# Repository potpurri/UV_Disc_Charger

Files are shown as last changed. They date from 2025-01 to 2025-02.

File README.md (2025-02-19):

## Overview

This project presents a UV disc charger designed to illuminate glow-in-the-dark disc golf discs using 100 UV LEDs.

The circuit is powered by a LiPo battery, which is charged through a TP4056 with DW01A protection. The LEDs are driven by a TPS63020 buck/boost converter, and the battery is charged via a USB-C port.

**Note:** This project is a work in progress, aimed at exploring and learning more about these technologies.

## Features

The board includes the following components:

- **TP4056**: Monitors and manages the charging process.
- **DW01A Protection**: Ensures safe charging of the LiPo battery.
- **TPS63020 Buck/Boost Converter**: Efficiently drives 100 UV LEDs.
- **USB-C Port**: Enables battery charging.
- **Adjustable Charging Current**: The charging current is set using resistor R9, with the following settings:

| Resistor (Ω) | Charging Current (mA) |
|---|---|
| 10k | 130 |
| 4k7 | 280 |
| 3k | 400 |
| 2k | 580 |
| 1k5 | 780 |
| 1k2 | 1000 |

Image showing the battery being charged at approximately 500mA:

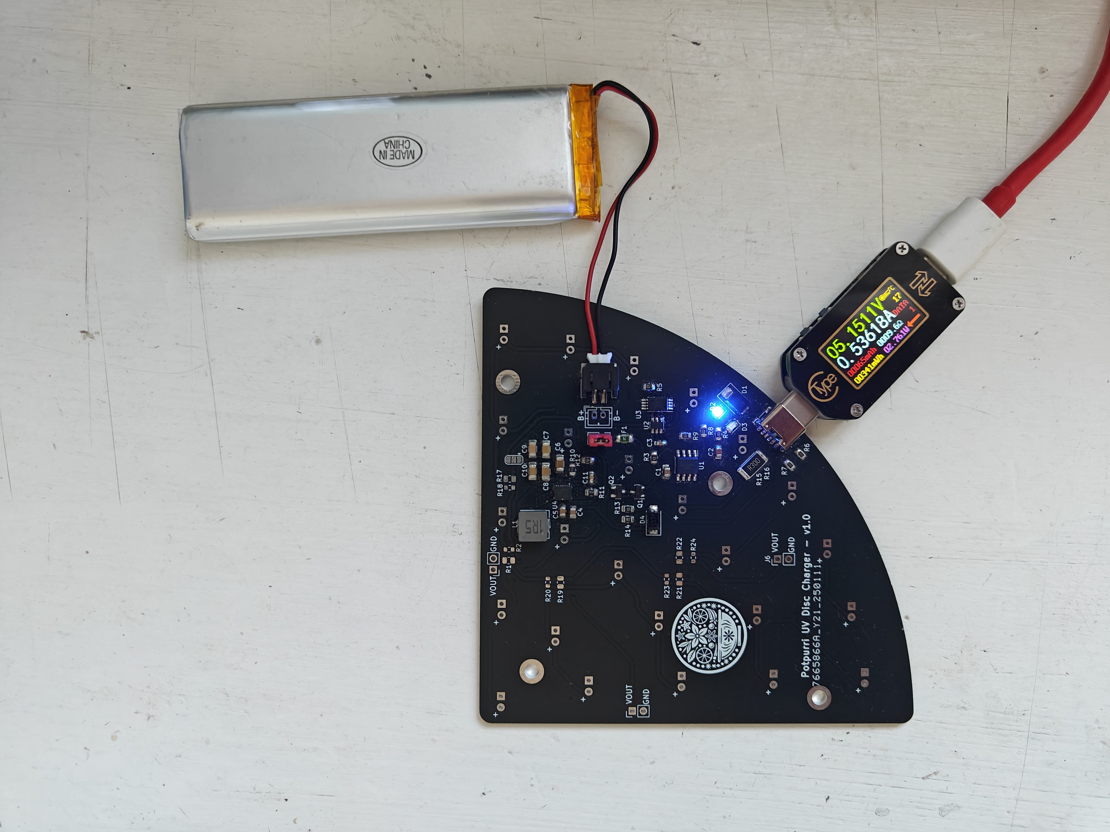
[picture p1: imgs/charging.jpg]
Charging


## Images

Below are renderings of the PCB:

3D render of the front view of the PCB

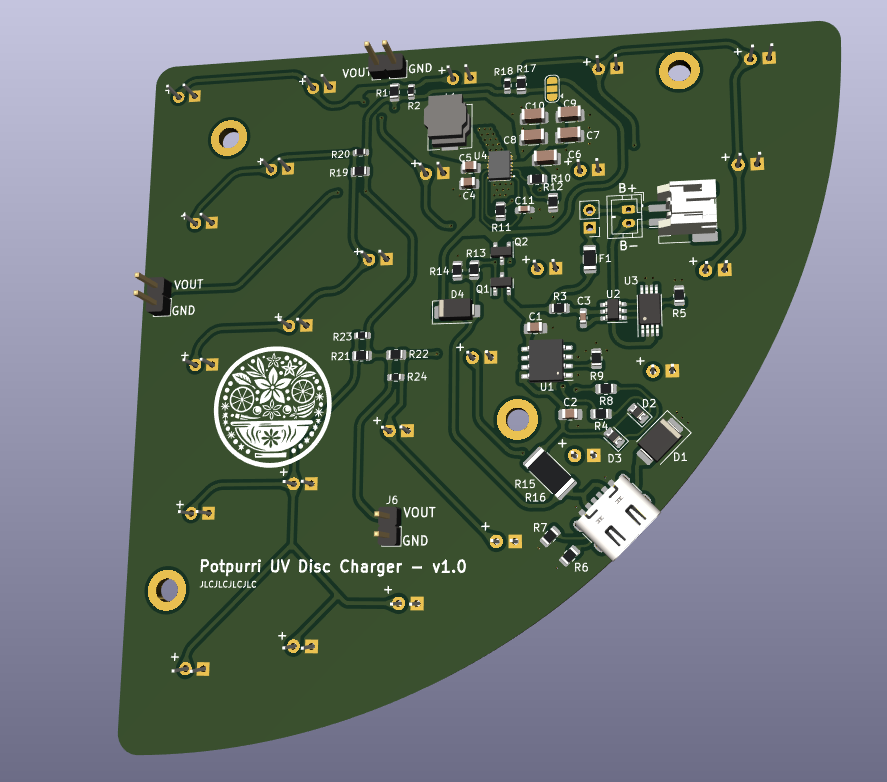
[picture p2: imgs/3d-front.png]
3D Front


3D render of the back view of the PCB

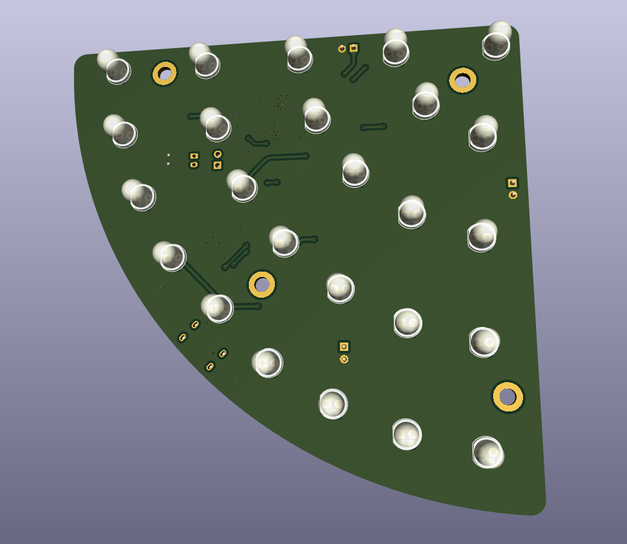
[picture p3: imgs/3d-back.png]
3D Back


Front view of the actual PCB

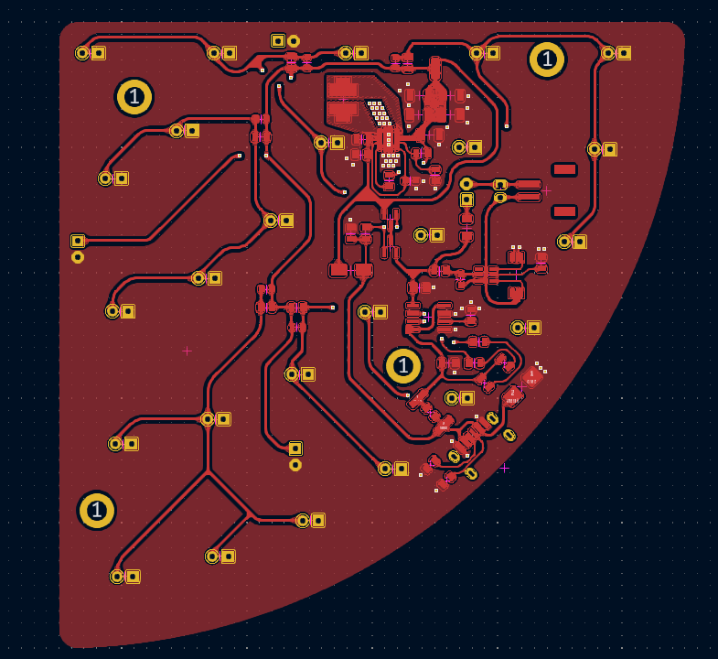
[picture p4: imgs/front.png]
Front


Back view of the actual PCB

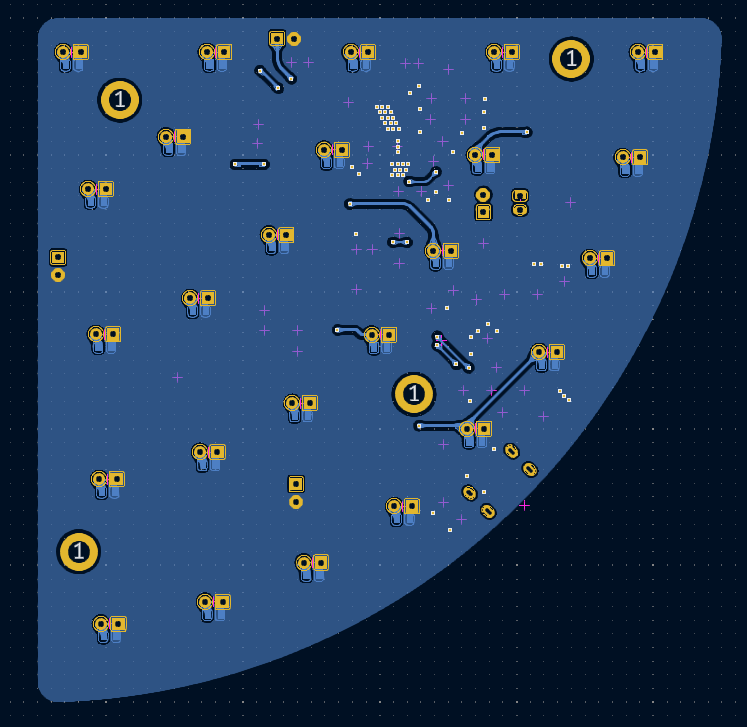
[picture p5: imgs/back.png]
Back


## Real PCB Images

Below are images of the actual PCB:

Front view of the real PCB

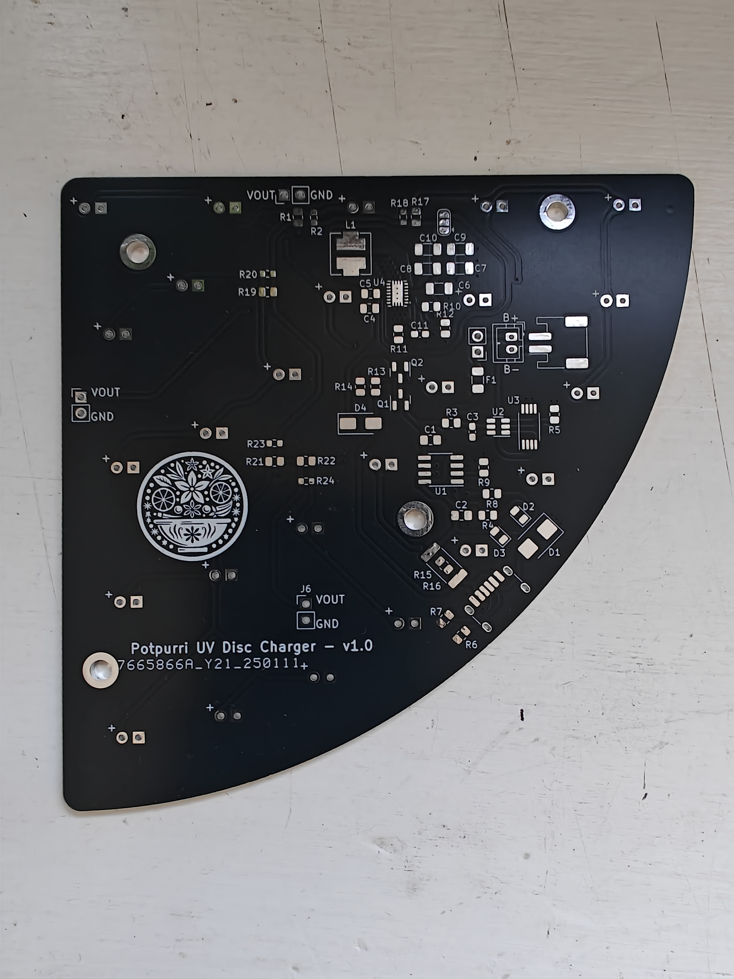
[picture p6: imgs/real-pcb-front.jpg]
Real PCB Front


Back view of the real PCB

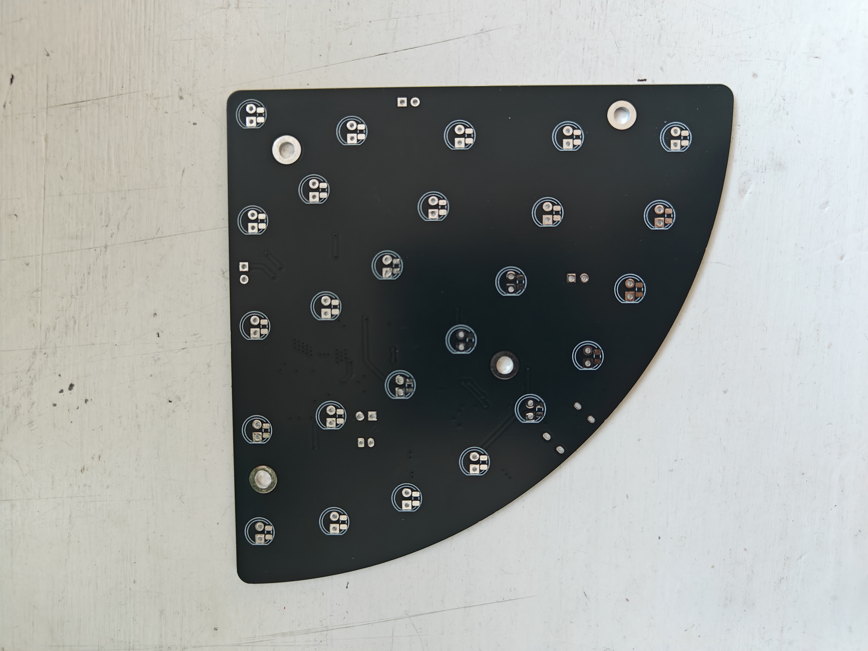
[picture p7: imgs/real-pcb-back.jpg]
Real PCB Back


## Full Assembly

**WORK IN PROGRESS**

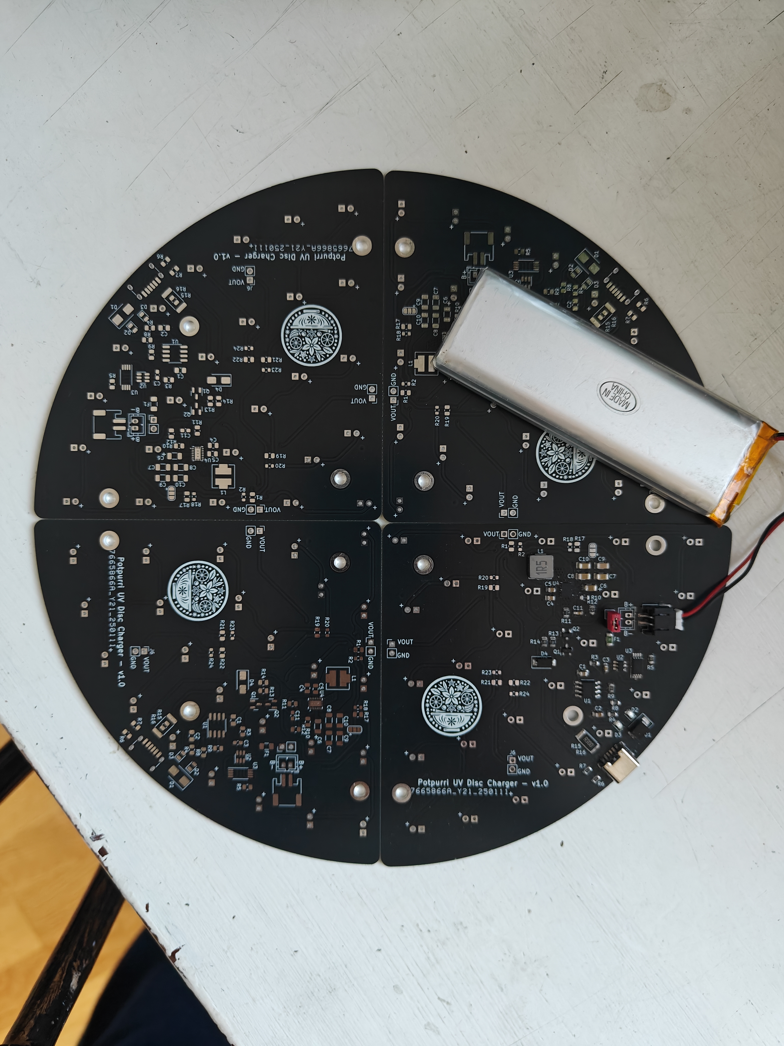
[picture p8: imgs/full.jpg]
Full Assembly


## Schematics

For detailed schematics, please refer to the [schematic PDF](imgs/schematic.pdf).

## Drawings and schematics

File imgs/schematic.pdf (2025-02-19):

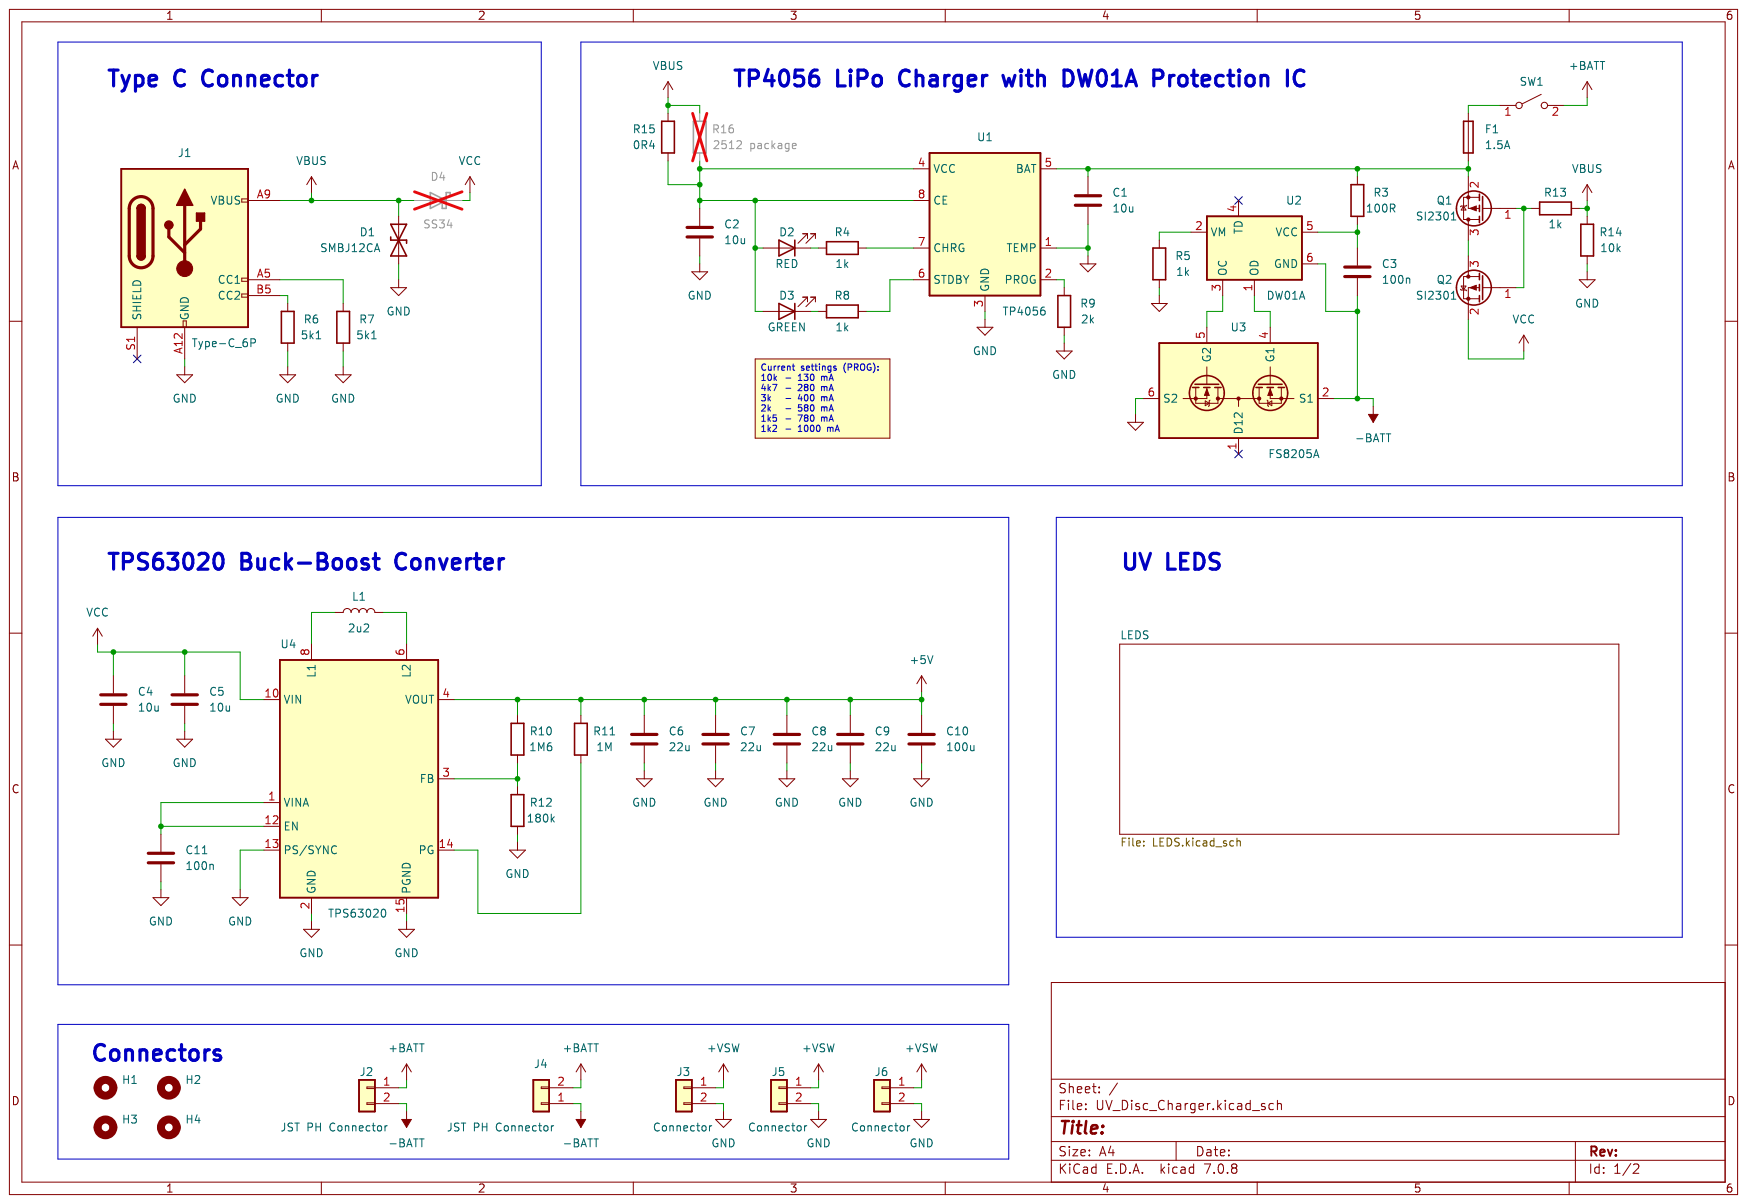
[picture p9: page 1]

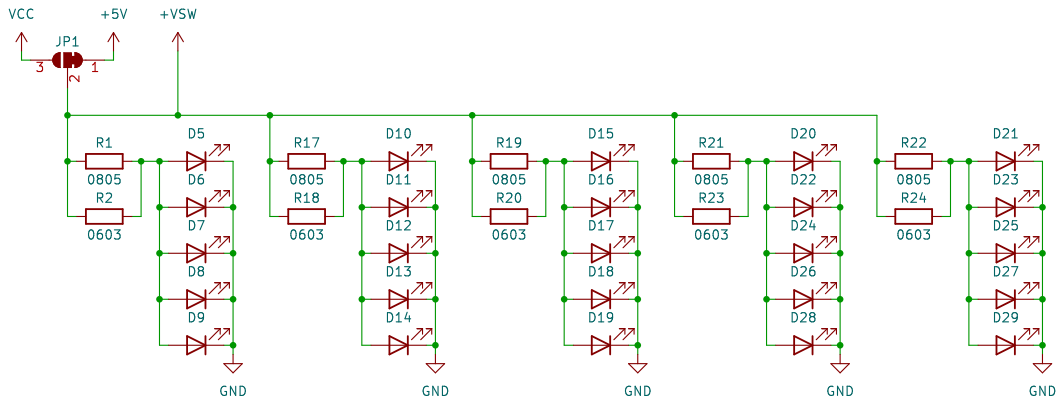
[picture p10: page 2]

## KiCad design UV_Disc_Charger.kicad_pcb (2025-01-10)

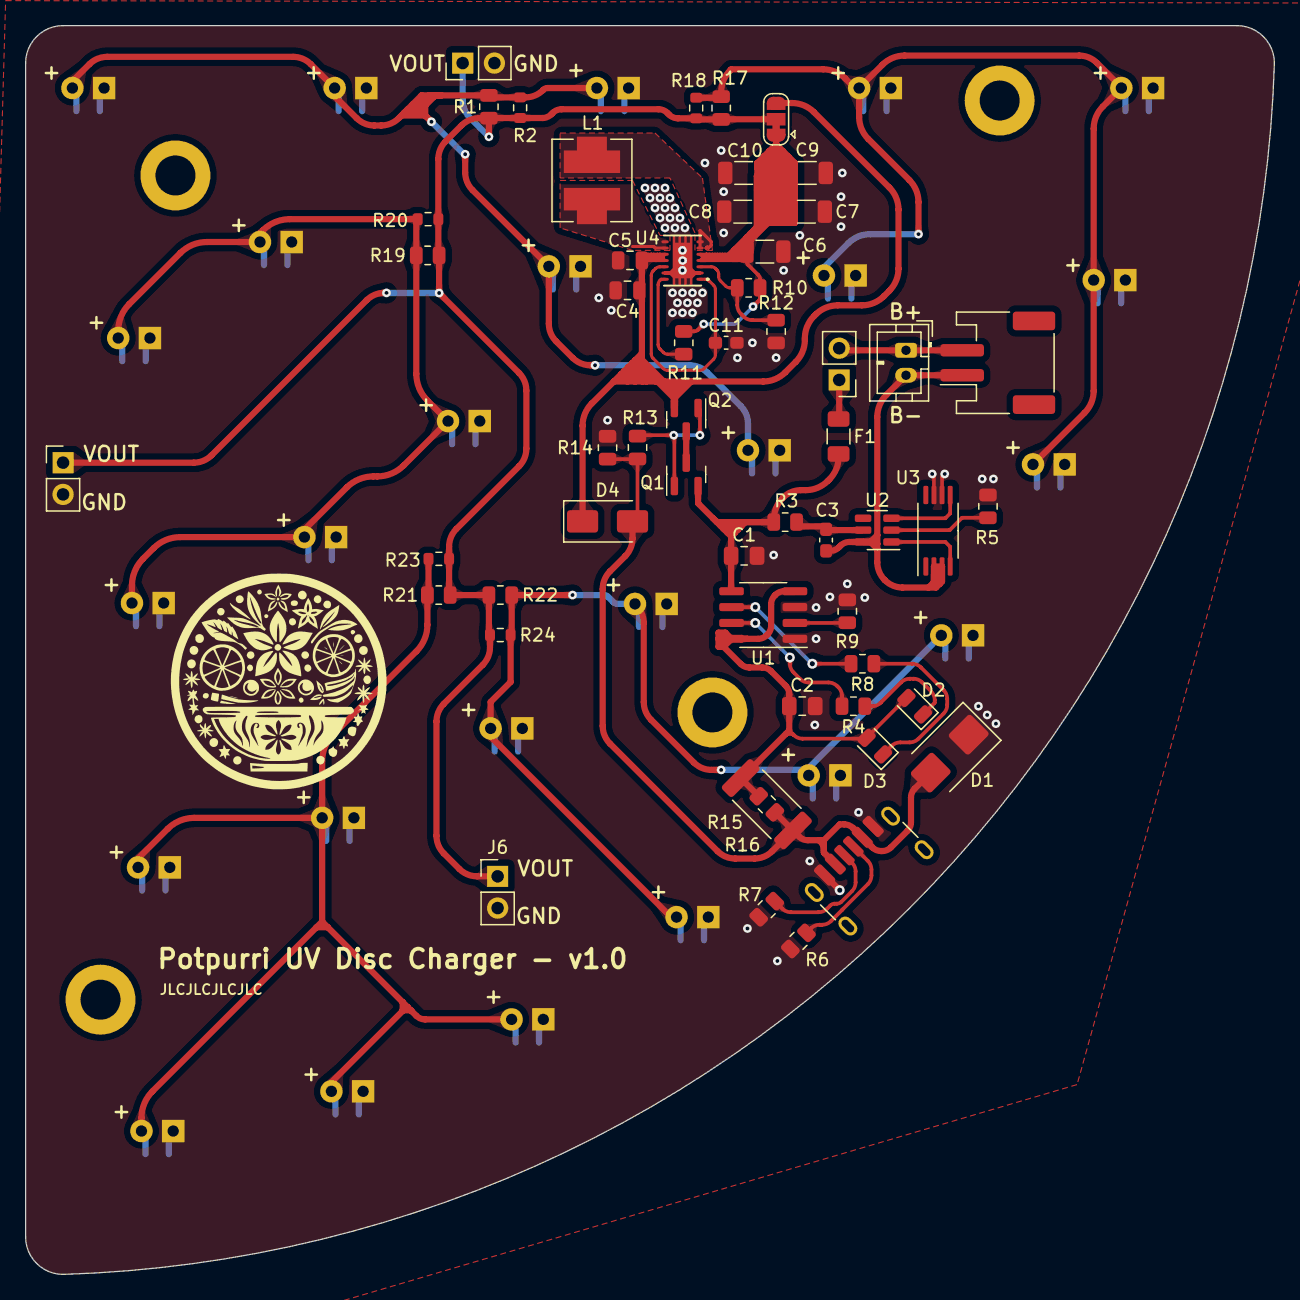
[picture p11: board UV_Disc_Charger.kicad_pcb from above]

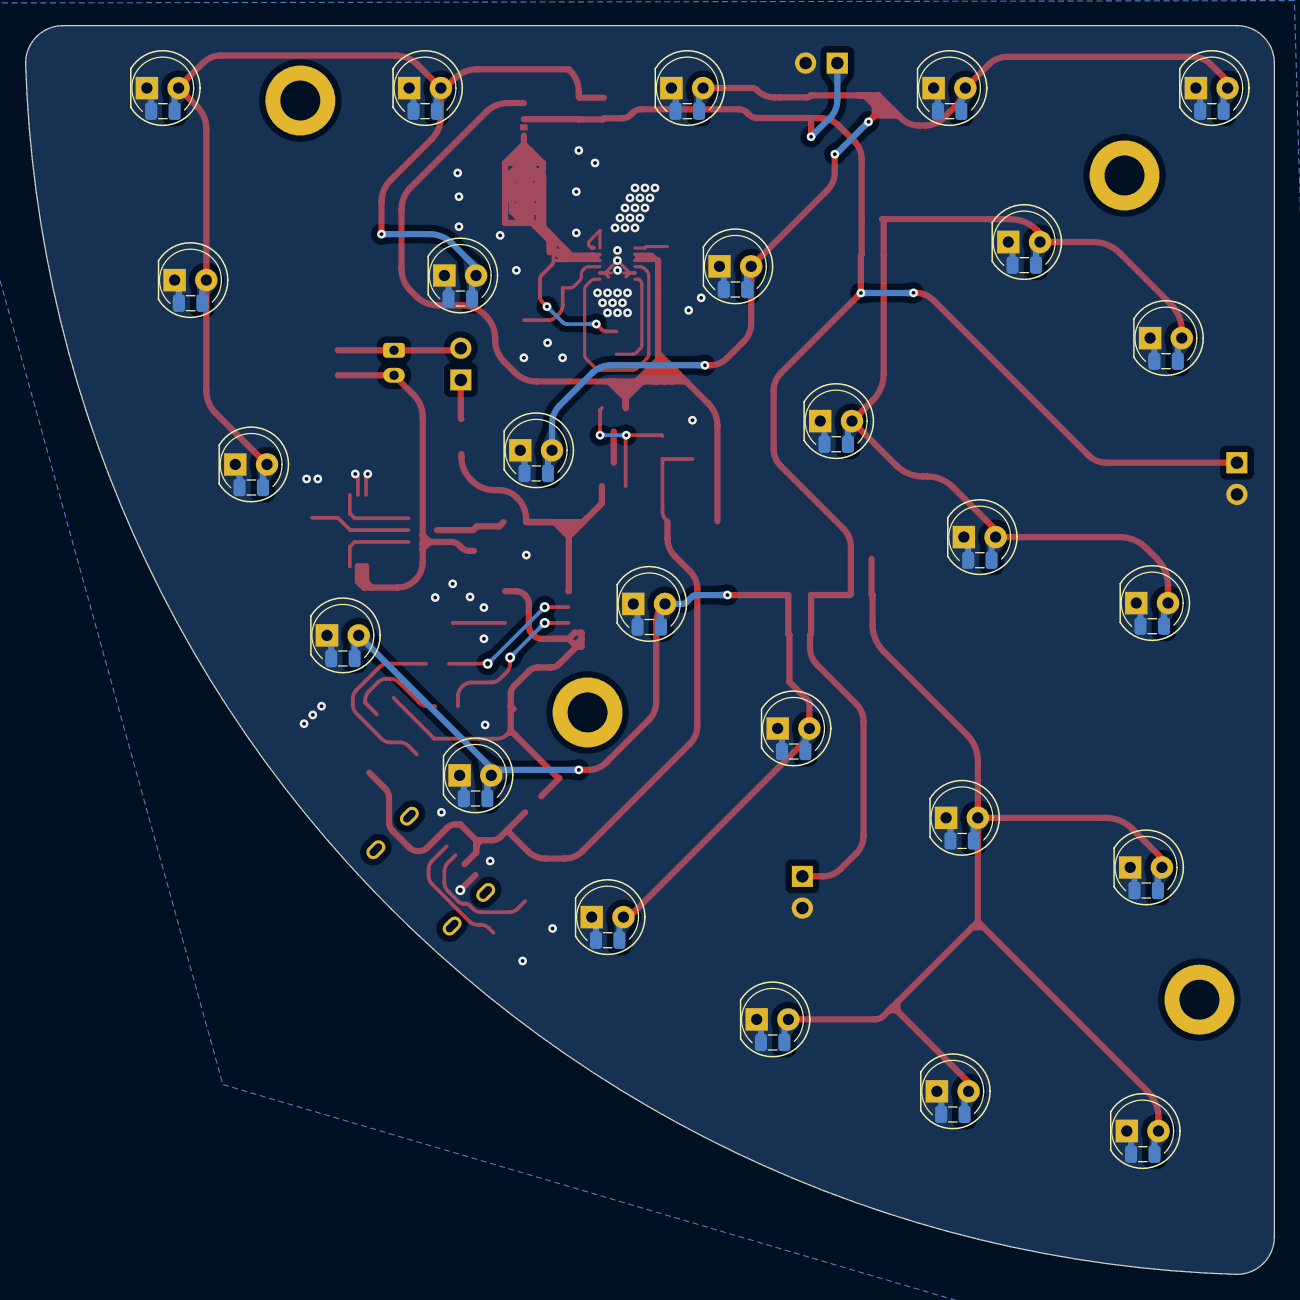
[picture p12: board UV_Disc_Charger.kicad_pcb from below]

Board: 2 copper layers, 100.0 x 100.0 mm, 84 parts (25 on the bottom side), 33 nets.

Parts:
C1, C2: 10u; C_0805_2012Metric_Pad1.18x1.45mm_HandSolder
C3, C11: 100n; C_0603_1608Metric_Pad1.08x0.95mm_HandSolder
C4, C5: 10u; C_0805_2012Metric
C6, C7, C8, C9: 22u; C_1206_3216Metric
C10: 100u; C_1206_3216Metric
D1: SMBJ12CA; D_SMB
D2: RED; D_0805_2012Metric
D3: GREEN; D_0805_2012Metric
D4: SS34; D_SMA
D5, D6, D7, D8, D9, D10, D11, D12, D13, D14, D15, D16, D17, D18, D19, D20, D21, D22, D23, D24, D25, D26, D27, D28, D29: LED; LED-ThroughHole-And-SMD0805
F1: 1.5A; Fuse_1206_3216Metric
H1, H2, H3, H4: MountingHole; MountingHole_3.2mm_M3_DIN965_Pad
J1: Type-C_6P; USB-C 6 Pin - Long pads
J2: JST PH Connector; JST_PH_B2B-PH-K_1x02_P2.00mm_Vertical
J3, J5, J6: Connector; PinHeader_1x02_P2.54mm_Vertical
J4: JST PH Connector; JST_PH_S2B-PH-SM4-TB_1x02-1MP_P2.00mm_Horizontal
JP1: SolderJumper_3_Bridged12; SolderJumper-3_P1.3mm_Bridged12_RoundedPad1.0x1.5mm
L1: 2u2; Combined CD43 + L 6.3x6.3
Q1, Q2: SI2301; SOT-23
R1, R17, R19, R21, R22: 0805; R_0805_2012Metric
R2, R18, R20, R23, R24: 0603; R_0603_1608Metric
R3: 100R; R_0805_2012Metric
R4, R5, R8, R13: 1k; R_0805_2012Metric
R6, R7: 5k1; R_0805_2012Metric
R9: 2k; R_0805_2012Metric
R10: 1M6; R_0805_2012Metric
R11: 1M; R_0805_2012Metric
R12: 180k; R_0805_2012Metric
R14: 10k; R_0805_2012Metric
R15: 0R4; R_0805_2012Metric
R16: 2512 package; R_2512_6332Metric
SW1: SW_SPST; PinHeader_1x02_P2.54mm_Vertical
U1: TP4056; SOP-8_3.76x4.96mm_P1.27mm
U2: DW01A; SOT-23-6
U3: FS8205A; TSSOP-8_4.4x3mm_P0.65mm
U4: TPS63020; QFN14-3X4MM

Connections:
+5V: C6.1, C7.1, C8.1, C9.1, C10.1, JP1.1 (A), R10.1, R11.1, U4.4 (VOUT), U4.5 (VOUT)
+BATT: J2.1, J4.2, SW1.2 (B)
+VSW: J3.1, J5.1, J6.1, JP1.2 (C), R1.1, R2.1, R17.1, R18.1, R19.1, R20.1, R21.1, R22.1, R23.1, R24.1
-BATT: C3.2, J2.2, J4.1, U2.6 (GND), U3.2 (S1), U3.3 (S1)
GND: C1.2, C2.2, C4.2, C5.2, C6.2, C7.2, C8.2, C9.2, C10.2, C11.2, D1.1 (A1), D5.1 (K), D6.1 (K), D7.1 (K), D8.1 (K), D9.1 (K), D10.1 (K), D11.1 (K), D12.1 (K), D13.1 (K), D14.1 (K), D15.1 (K), D16.1 (K), D17.1 (K), D18.1 (K), D19.1 (K), D20.1 (K), D21.1 (K), D22.1 (K), D23.1 (K), D24.1 (K), D25.1 (K), D26.1 (K), D27.1 (K), D28.1 (K), D29.1 (K), J1.A12 (GND), J1.B12 (GND), J3.2, J5.2, J6.2, R5.2, R6.2, R7.2, R9.2, R12.2, R14.2, U1.1 (TEMP), U1.3 (GND), U3.6 (S2), U3.7 (S2), U4.2 (GND), U4.13 (PS/SYNC), U4.15 (PGND), U4.16 (PGND), U4.17 (PGND), U4.18 (PGND), U4.19 (PGND), U4.20 (PGND), U4.21 (PGND), U4.22 (PGND), U4.23 (PGND)
unnamed: C2.1, D2.2 (A), D3.2 (A), R15.1, R16.1, U1.4 (VCC), U1.8 (CE)
unnamed: D2.1 (K), R4.1
unnamed: D3.1 (K), R8.1
unnamed: D5.2 (A), D6.2 (A), D7.2 (A), D8.2 (A), D9.2 (A), R1.2, R2.2
unnamed: D10.2 (A), D11.2 (A), D12.2 (A), D13.2 (A), D14.2 (A), R17.2, R18.2
unnamed: D15.2 (A), D16.2 (A), D17.2 (A), D18.2 (A), D19.2 (A), R19.2, R20.2
unnamed: D20.2 (A), D22.2 (A), D24.2 (A), D26.2 (A), D28.2 (A), R21.2, R23.2
unnamed: D21.2 (A), D23.2 (A), D25.2 (A), D27.2 (A), D29.2 (A), R22.2, R24.2
unnamed: J1.A5 (CC1), R7.1
unnamed: J1.B5 (CC2), R6.1
unnamed: L1.1, U4.8 (L1), U4.9 (L1)
unnamed: L1.2, U4.6 (L2), U4.7 (L2)
unnamed: Q1.3 (D), Q2.3 (D)
unnamed: Q1.1 (G), Q2.1 (G), R13.1
unnamed: C1.1, F1.2, Q1.2 (S), R3.2, U1.5 (BAT)
unnamed: F1.1, SW1.1 (A)
unnamed: R4.2, U1.7 (CHRG)
unnamed: R9.1, U1.2 (PROG)
unnamed: R8.2, U1.6 (STDBY)
unnamed: U2.3 (OC), U3.5 (G2)
unnamed: U2.1 (OD), U3.4 (G1)
unnamed: C3.1, R3.1, U2.5 (VCC)
unnamed: R5.1, U2.2 (VM)
unnamed: C11.1, U4.1 (VINA), U4.12 (EN)
unnamed: R10.2, R12.1, U4.3 (FB)
unnamed: R11.2, U4.14 (PG)
VBUS: D1.2 (A2), D4.2 (A), J1.A9 (VBUS), J1.B9 (VBUS), R13.2, R14.1, R15.2, R16.2
VCC: C4.1, C5.1, D4.1 (K), JP1.3 (B), Q2.2 (S), U4.10 (VIN), U4.11 (VIN)

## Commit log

2024-11-15 layout started
    [LEDS.kicad_sch, UV_Disc_Charger.kicad_pcb, UV_Disc_Charger.kicad_sch]
2025-01-10 added manufacturing files
    [LEDS.kicad_sch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]
